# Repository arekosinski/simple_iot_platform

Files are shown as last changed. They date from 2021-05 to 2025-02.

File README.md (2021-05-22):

# simple_iot_system
System for gathering temperature and humidity based on SAM D21, Arduino and nrf24l01. Also Raspberry Pi is involved:)

# Parts of the system
1. Board with MCU, temperature & humidity sensor and radio (nrf24l01)
    * Board is based on Microchip SAM D21 microcontroller
    * You can use Arduino framework to play with this board (this board is Arduino Zero compatible - see more for reference in this [repo](https://github.com/arekosinski/samd21_minimal_board))
    * Radio module slot prepared for nrf24l01
    * Sensor for temp & humidity: SHT31
    * schematic is available in `sensor_schematic` directory. Board design is also attached
    * This board should take around 8-10uA in sleep mode
    * Other components
        * MCP16252 as voltage controller (as boost up). Designed for 2xAA batteries. Input voltage shouldn't excess 3.4V). Board voltage is 3V.
        * MOSFET On Semi FDC6306P (two on board) is used as power controller for radio module and other devices (3 gates)
        * One gate of FDC6306P is used as polarization protection between power source and MCP16252.
2. `sensor_node` - Code responsibile for communication with RF-RPI proxy
3. `rf_rpi_proxy` - Code for the board to act as a UART proxy to Raspberry Pi
4. `rpi_uart_client` - Python UART client resposible for translating received messages

# System diagram

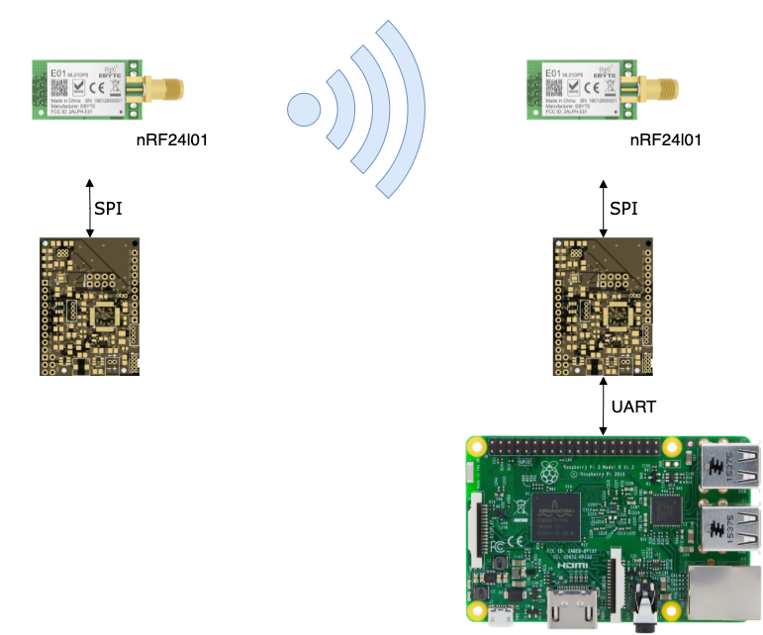
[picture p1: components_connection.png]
Components connection


# Why?
Just for fun :)

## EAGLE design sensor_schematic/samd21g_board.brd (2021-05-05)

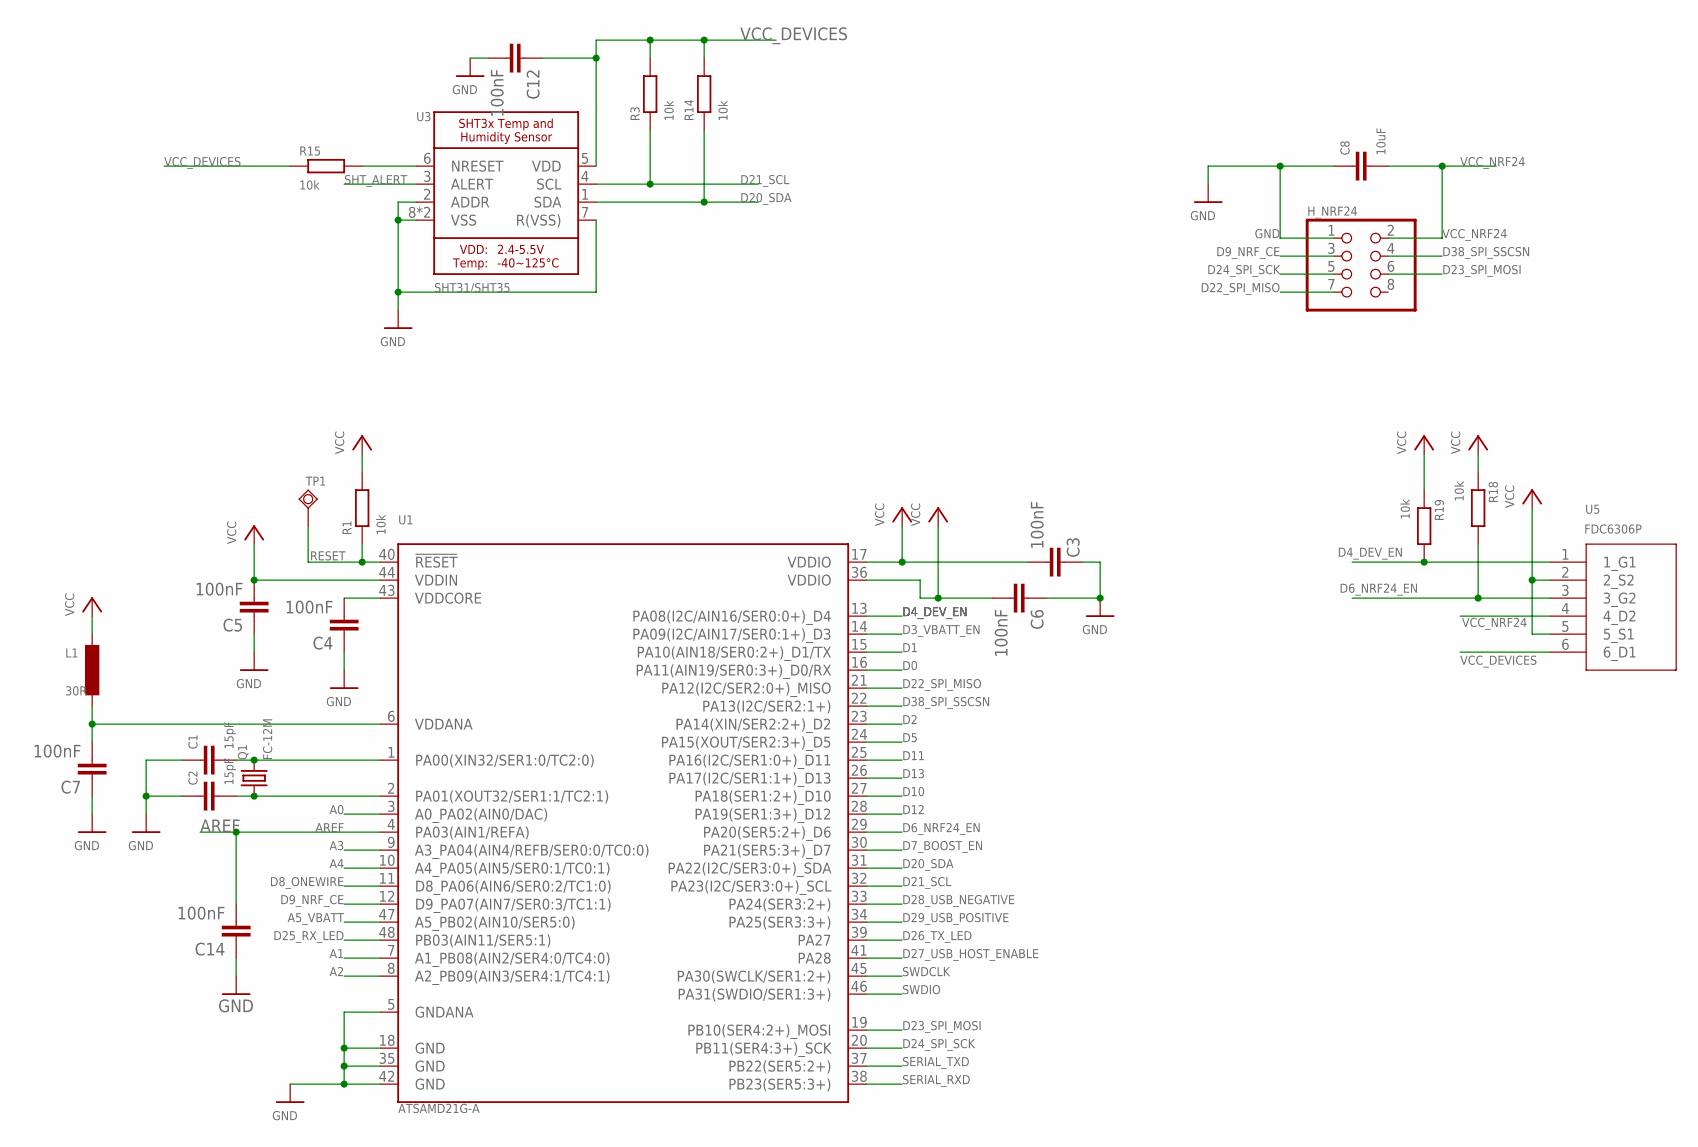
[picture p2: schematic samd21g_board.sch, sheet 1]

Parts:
C1, C2: 15pF; C0402
C3, C4, C5, C6, C7, C12, C14: 100nF; C0603
C8: 10uF; C0805
H_NRF24: PINHD-2X04_2.54; 2X04
L1: 30R; L3225M
Q1: FC-12M
R1, R3, R14, R15, R18, R19: 10k; R0805
TP1: TPSQTP13SQ; TP13SQ
U1: ATSAMD21G-A; TQFP-48
U3: SHT31/SHT35; SHT3X_DFN8
U5: FDC6306P; TSOT23-6_419BL_ONS

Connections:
A0: U1.3 (A0_PA02(AIN0/DAC)); also elsewhere on the board
A1: U1.7 (A1_PB08(AIN2/SER4:0/TC4:0)); also elsewhere on the board
A2: U1.8 (A2_PB09(AIN3/SER4:1/TC4:1)); also elsewhere on the board
A3: U1.9 (A3_PA04(AIN4/REFB/SER0:0/TC0:0)); also elsewhere on the board
A4: U1.10 (A4_PA05(AIN5/SER0:1/TC0:1)); also elsewhere on the board
A5_VBATT: U1.47 (A5_PB02(AIN10/SER5:0)); also elsewhere on the board
AREF: C14.2, U1.4 (PA03(AIN1/REFA)); also elsewhere on the board
D0: U1.16 (PA11(AIN19/SER0:3+)_D0/RX); also elsewhere on the board
D1: U1.15 (PA10(AIN18/SER0:2+)_D1/TX); also elsewhere on the board
D2: U1.23 (PA14(XIN/SER2:2+)_D2); also elsewhere on the board
D3_VBATT_EN: U1.14 (PA09(I2C/AIN17/SER0:1+)_D3); also elsewhere on the board
D4_DEV_EN: R19.2, U1.13 (PA08(I2C/AIN16/SER0:0+)_D4), U5.1 (1_G1)
D5: U1.24 (PA15(XOUT/SER2:3+)_D5); also elsewhere on the board
D6_NRF24_EN: R18.2, U1.29 (PA20(SER5:2+)_D6), U5.3 (3_G2)
D7_BOOST_EN: U1.30 (PA21(SER5:3+)_D7); also elsewhere on the board
D8_ONEWIRE: U1.11 (D8_PA06(AIN6/SER0:2/TC1:0)); also elsewhere on the board
D9_NRF_CE: H_NRF24.3, U1.12 (D9_PA07(AIN7/SER0:3/TC1:1))
D10: U1.27 (PA18(SER1:2+)_D10); also elsewhere on the board
D11: U1.25 (PA16(I2C/SER1:0+)_D11); also elsewhere on the board
D12: U1.28 (PA19(SER1:3+)_D12); also elsewhere on the board
D13: U1.26 (PA17(I2C/SER1:1+)_D13); also elsewhere on the board
D20_SDA: R14.1, U1.31 (PA22(I2C/SER3:0+)_SDA), U3.1 (SDA); also elsewhere on the board
D21_SCL: R3.1, U1.32 (PA23(I2C/SER3:0+)_SCL), U3.4 (SCL); also elsewhere on the board
D22_SPI_MISO: H_NRF24.7, U1.21 (PA12(I2C/SER2:0+)_MISO); also elsewhere on the board
D23_SPI_MOSI: H_NRF24.6, U1.19 (PB10(SER4:2+)_MOSI); also elsewhere on the board
D24_SPI_SCK: H_NRF24.5, U1.20 (PB11(SER4:3+)_SCK); also elsewhere on the board
D25_RX_LED: U1.48 (PB03(AIN11/SER5:1)); also elsewhere on the board
D26_TX_LED: U1.39 (PA27); also elsewhere on the board
D27_USB_HOST_ENABLE: U1.41 (PA28); also elsewhere on the board
D28_USB_NEGATIVE: U1.33 (PA24(SER3:2+)); also elsewhere on the board
D29_USB_POSITIVE: U1.34 (PA25(SER3:3+)); also elsewhere on the board
D38_SPI_SSCSN: H_NRF24.4, U1.22 (PA13(I2C/SER2:1+)); also elsewhere on the board
GND: C1.1, C2.1, C3.1, C4.1, C5.1, C6.1, C7.1, C8.1, C12.2, C14.1, H_NRF24.1, U1.5 (GNDANA), U1.18 (GND), U1.35 (GND), U1.42 (GND), U3.2 (ADDR), U3.7 (R(VSS)), U3.8 (VSS), U3.THERMAL (VSS); also elsewhere on the board
unnamed: C1.2, Q1.2, U1.1 (PA00(XIN32/SER1:0/TC2:0))
unnamed: C2.2, Q1.1, U1.2 (PA01(XOUT32/SER1:1/TC2:1))
unnamed: R15.2, U3.6 (NRESET)
unnamed: C7.2, L1.2, U1.6 (VDDANA)
unnamed: C4.2, U1.43 (VDDCORE)
RESET: R1.1, TP1.TP, U1.40 (!RESET!); also elsewhere on the board
SERIAL_RXD: U1.38 (PB23(SER5:3+)); also elsewhere on the board
SERIAL_TXD: U1.37 (PB22(SER5:2+)); also elsewhere on the board
SHT_ALERT: U3.3 (ALERT); also elsewhere on the board
SWDCLK: U1.45 (PA30(SWCLK/SER1:2+)); also elsewhere on the board
SWDIO: U1.46 (PA31(SWDIO/SER1:3+)); also elsewhere on the board
VCC: C3.2, C5.2, C6.2, L1.1, R1.2, R18.1, R19.1, U1.17 (VDDIO), U1.36 (VDDIO), U1.44 (VDDIN), U5.2 (2_S2), U5.5 (5_S1); also elsewhere on the board
VCC_DEVICES: C12.1, R3.2, R14.2, R15.1, U3.5 (VDD), U5.6 (6_D1); also elsewhere on the board
VCC_NRF24: C8.2, H_NRF24.2, U5.4 (4_D2)

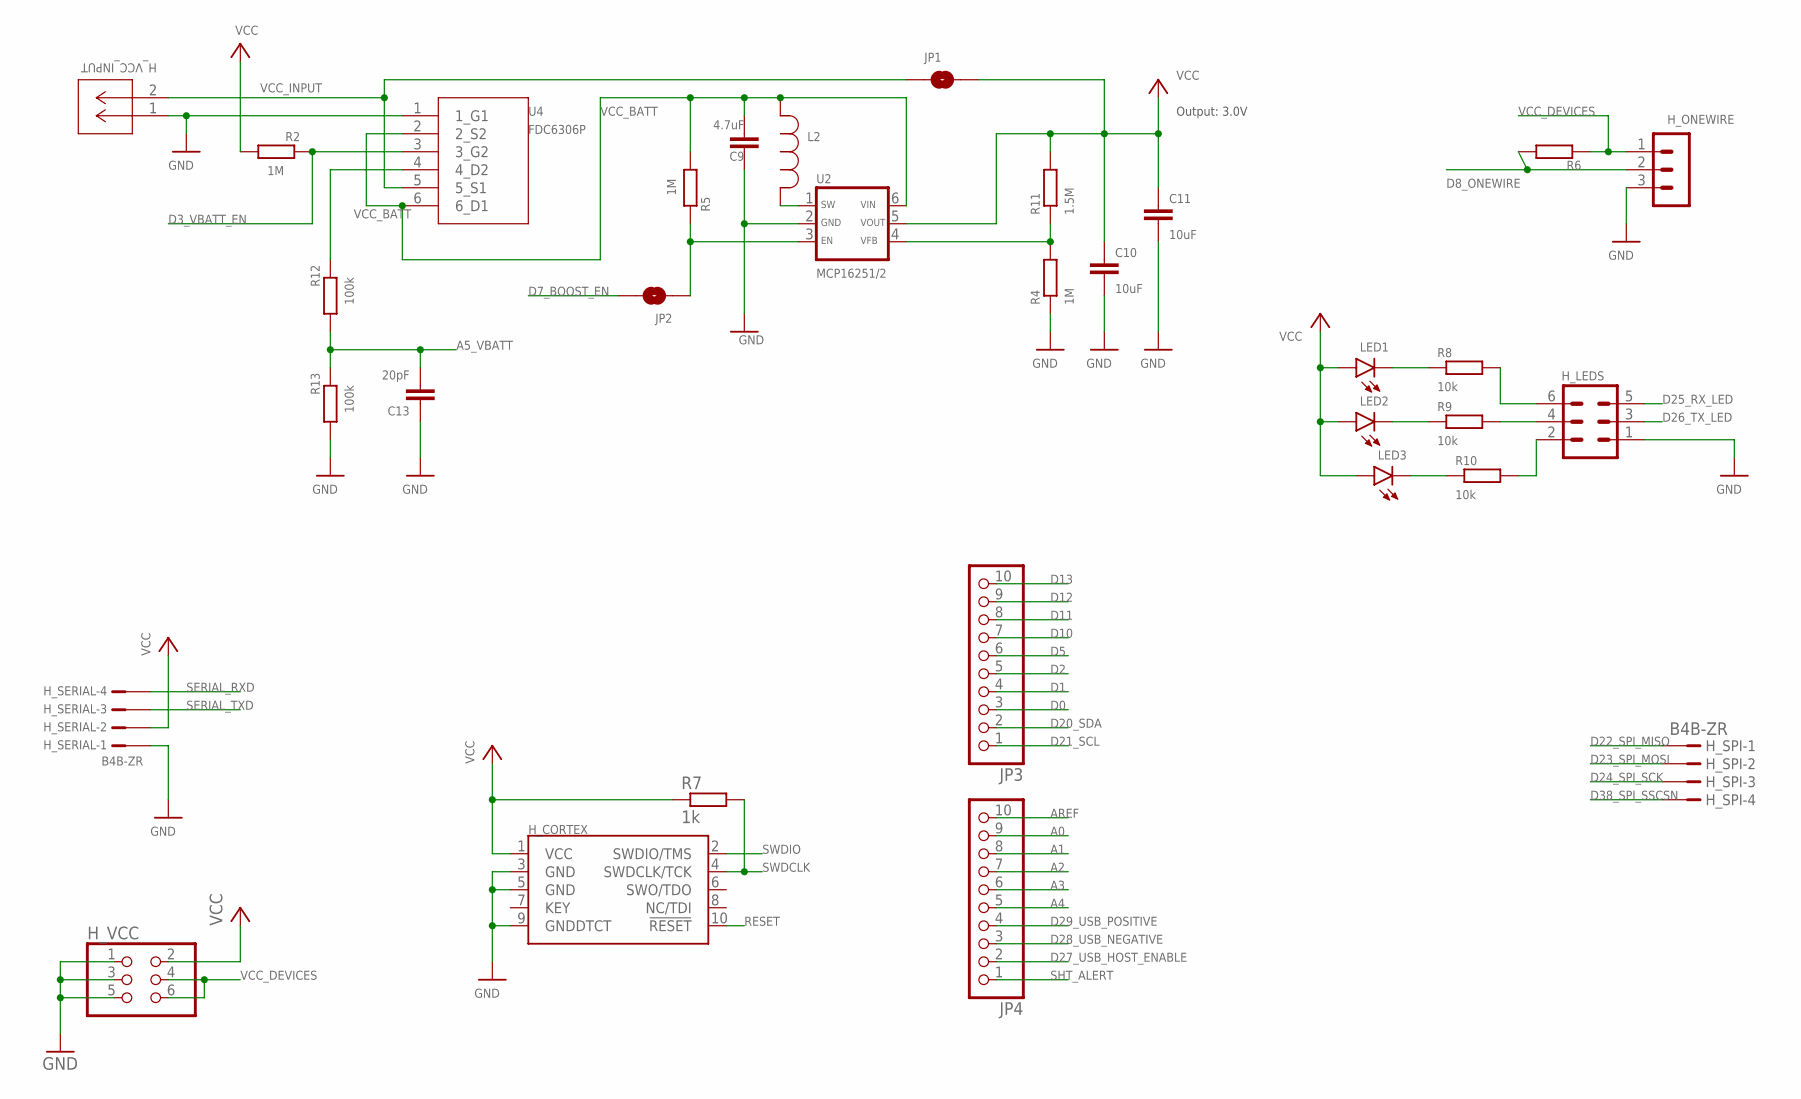
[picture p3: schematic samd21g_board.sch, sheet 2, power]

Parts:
C9: 4.7uF; C0805
C10, C11: 10uF; C0805
C13: 20pF; C0402
H_CORTEX: CORTEX_JTAG_DEBUG_PTH; 2X5-PTH-1.27MM
H_LEDS: M_2R03_50MIL-V2
H_ONEWIRE: M_1R03_50MIL-V
H_SERIAL: B4B-ZR
H_SPI: B4B-ZR
H_VCC: PINHD-2X03_2.54; 2X03
H_VCC_INPUT: S2B-ZR; CONN_S2B-ZR_JST
JP1, JP2: JUMPER-SMT_2_NO_NO-SILK; SMT-JUMPER_2_NO_NO-SILK
JP3, JP4: PINHD-1X10_2.54-S; 1X10-S
L2: 4.7uH; IND_CDRH3D16-4R7NC_SUM
LED1, LED2, LED3: LEDCHIP-LED0805; CHIP-LED0805
R2, R4, R5: 1M; R0805
R6: 4.7k; R0805
R7: 1k; R0805
R8, R9, R10: 10k; R0805
R11: 1.5M; R0805
R12, R13: 100k; R0805
U2: MCP16251/2; SOT-23-6
U4: FDC6306P; TSOT23-6_419BL_ONS

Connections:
A0: JP4.9; also elsewhere on the board
A1: JP4.8; also elsewhere on the board
A2: JP4.7; also elsewhere on the board
A3: JP4.6; also elsewhere on the board
A4: JP4.5; also elsewhere on the board
A5_VBATT: C13.2, R12.1, R13.2; also elsewhere on the board
AREF: JP4.10; also elsewhere on the board
D0: JP3.3; also elsewhere on the board
D1: JP3.4; also elsewhere on the board
D2: JP3.5; also elsewhere on the board
D3_VBATT_EN: R2.2, U4.3 (3_G2); also elsewhere on the board
D5: JP3.6; also elsewhere on the board
D7_BOOST_EN: JP2.2; also elsewhere on the board
D8_ONEWIRE: H_ONEWIRE.2, R6.2; also elsewhere on the board
D10: JP3.7; also elsewhere on the board
D11: JP3.8; also elsewhere on the board
D12: JP3.9; also elsewhere on the board
D13: JP3.10; also elsewhere on the board
D20_SDA: JP3.2; also elsewhere on the board
D21_SCL: JP3.1; also elsewhere on the board
D22_SPI_MISO: H_SPI.1; also elsewhere on the board
D23_SPI_MOSI: H_SPI.2; also elsewhere on the board
D24_SPI_SCK: H_SPI.3; also elsewhere on the board
D25_RX_LED: H_LEDS.5; also elsewhere on the board
D26_TX_LED: H_LEDS.3; also elsewhere on the board
D27_USB_HOST_ENABLE: JP4.2; also elsewhere on the board
D28_USB_NEGATIVE: JP4.3; also elsewhere on the board
D29_USB_POSITIVE: JP4.4; also elsewhere on the board
D38_SPI_SSCSN: H_SPI.4; also elsewhere on the board
GND: C9.1, C10.2, C11.2, C13.1, H_CORTEX.3 (GND), H_CORTEX.5 (GND), H_CORTEX.9 (GNDDTCT), H_LEDS.1, H_ONEWIRE.3, H_SERIAL.1, H_VCC.1, H_VCC.3, H_VCC.5, H_VCC_INPUT.1, R4.1, R13.1, U2.2 (GND), U4.1 (1_G1); also elsewhere on the board
unnamed: H_LEDS.4, R9.2
unnamed: LED2.C, R9.1
unnamed: LED3.C, R10.1
unnamed: LED1.C, R8.1
unnamed: H_LEDS.6, R8.2
unnamed: JP2.1, R5.2, U2.3 (EN)
unnamed: R12.2, U4.4 (4_D2)
unnamed: H_LEDS.2, R10.2
unnamed: R4.2, R11.1, U2.4 (VFB)
unnamed: L2.1, U2.1 (SW)
RESET: H_CORTEX.10 (!RESET); also elsewhere on the board
SERIAL_RXD: H_SERIAL.4; also elsewhere on the board
SERIAL_TXD: H_SERIAL.3; also elsewhere on the board
SHT_ALERT: JP4.1; also elsewhere on the board
SWDCLK: H_CORTEX.4 (SWDCLK/TCK), R7.2; also elsewhere on the board
SWDIO: H_CORTEX.2 (SWDIO/TMS); also elsewhere on the board
VCC: C10.1, C11.1, H_CORTEX.1 (VCC), H_SERIAL.2, H_VCC.2, JP1.2, LED1.A, LED2.A, LED3.A, R2.1, R7.1, R11.2, U2.5 (VOUT); also elsewhere on the board
VCC_BATT: C9.2, L2.2, R5.1, U2.6 (VIN), U4.2 (2_S2), U4.6 (6_D1)
VCC_DEVICES: H_ONEWIRE.1, H_VCC.4, H_VCC.6, R6.1; also elsewhere on the board
VCC_INPUT: H_VCC_INPUT.2, JP1.1, U4.5 (5_S1)

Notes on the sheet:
Output: 3.0V

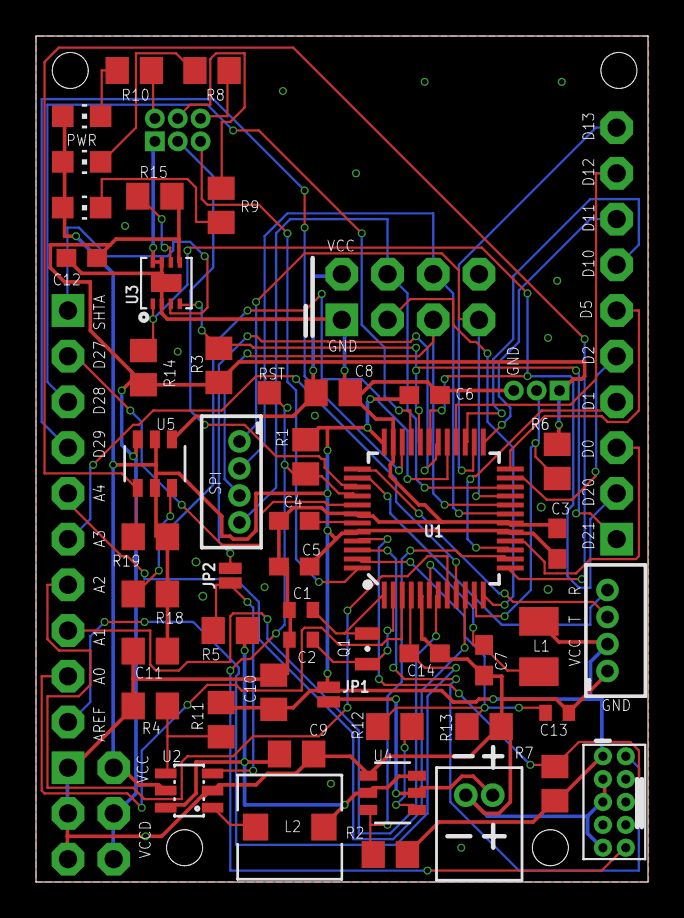
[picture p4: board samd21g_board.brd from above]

Board: 2 copper layers, 34.0 x 47.0 mm, 55 parts (0 on the bottom side), 59 nets.

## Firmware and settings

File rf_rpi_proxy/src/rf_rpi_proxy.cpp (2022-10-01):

#include <Arduino.h>

// define board pins according to arduino pins schema
#define LED_BUILTIN      (25ul)   // User controlled LED1 Arduino: D25 / Board: D25_RX_LED/PB03
#define LED_BUILTIN_1    LED_BUILTIN
#define LED_BULITIN_2    (26ul)   // User controlled LED2 Arduino: D26 / Board: D26_TX_LED/PA27
#define PIN_RADIO_EN     (6ul)	 // Pin to control radio power MOSFET / Arduino: D6 / Board: D6_NRF24_EN/PA20

// system behavior
#define SERIAL_BAUDS     (115200ul)	// UART Speed for debugging header (Arduino: Serial object)
#define RPI_SERIAL_BAUDS (230400ul) // UART Speed for communication with Raspberry Pi (Arduino: Serial1 object)

uint8_t is_debug_initialized = 0;

// headers for NRF24 library
#include <SPI.h>
#include "RF24.h"

// communication
#define R_PIN_CE         (9ul)		  // Arduino: D9 / Board: D9_NRF_CE/PA07
#define R_PIN_CSN        (38ul)		  // Arduino: D38 / Board: D38_SPI_SSCSN/PA13
#define R_ADDR_RX        (0x696900)	  // Address on which we must listen to get messages from remote nodes (on remote nodes this is TX address)
#define R_ADDR_WIDTH     (3ul)		  // We can limit frame by using shorter address
#define R_CHANNEL        (20ul)		  // Channel number from 2.4GHz range
#define R_POWER_LVL      RF24_PA_MAX  // Output power during sending
#define R_DATA_RATE      RF24_250KBPS // Data rate used over the air
#define R_MSG_DELAY      (50ul)		  // Check description of setRetries function for meaning of this value
#define R_MSG_RETRIES    (10ul)	      // Check description of setRetries function for meaning of this value

RF24 radio(R_PIN_CE, R_PIN_CSN);

/*
Enum with definition of possible system restart. User should be aware of what kind of reboot occurred.
1 - System reset
2 - External reset requested (some one pushedreset button)
3 - BOD 3.3V
4 - BOD 1.2V
5 - Normal power on reset - system is starting by its standard procedure
6 - WDT Reset
99 - Unknown / very very sad face :(
*/
typedef enum {
    /** (0) System reset */
    RBT_SYSTEM = 0,
    /** (1) External reset (reset pin) */
    RBT_EXTERNAL_RESET,
    /** (2) BOD 3.3V */
    RBT_BOD3V3,
    /** (3) BOD 1.2V */
    RBT_BOD1V2,
    /** (4) Normaln power on reset - standard */
    RBT_STARTUP,
    /** (6) WDT */
    RBT_WDT,
    RBT_UNKNOWN = 99
} startup_code_ref;

//
// debugging 
template <typename... T>
void debug_me(const char *str, T... args) {
#ifdef DEBUG_ENABLED
	if ( is_debug_initialized == 1 ) {
		int len = snprintf(NULL, 0, str, args...);
		if (len) {
			char buff[len] = {0};
			sprintf(buff, str, args...);
			Serial.print(buff);
		};
		Serial.println();
	};
#endif
}

void enable_debug_mode() {
#ifdef DEBUG_ENABLED
	PM->APBCMASK.reg |= PM_APBCMASK_SERCOM5;	
    Serial.begin(SERIAL_BAUDS);
	debug_me("----------------------------");
	debug_me("Debug enabled");
	is_debug_initialized = 1;
#endif
}

void disable_debug_mode() {
#ifdef DEBUG_ENABLED
	Serial.end();
	is_debug_initialized = 0;
#endif
}
// END debugging

startup_code_ref get_last_reset_cause() {
	if (PM->RCAUSE.bit.SYST == 1)
	{
		debug_me("Reboot: Reset requested by system");
		return RBT_SYSTEM;
	};
	if (PM->RCAUSE.reg & PM_RCAUSE_WDT)
	{
		debug_me("Reboot: WDT");
		return RBT_WDT;
	};
	if (PM->RCAUSE.bit.EXT == 1)
	{
		debug_me("Reboot: External reset requested");
		return RBT_EXTERNAL_RESET;
	};
	if (PM->RCAUSE.bit.BOD33 == 1)
	{
		debug_me("Reboot: Reset brown out 3.3V");
		return RBT_BOD3V3;
	};
	if (PM->RCAUSE.bit.BOD12 == 1)
	{
		debug_me("Reboot: Reset brown out 1.2v");
		return RBT_BOD1V2;
	};
	if (PM->RCAUSE.bit.POR == 1)
	{
		debug_me("Reboot: Normal power on reset");
		return RBT_STARTUP;
	};
	debug_me("Reboot: unknown reason");
	return RBT_UNKNOWN;
}

//
// basic function to shorthand (wrap) enabling and disabling devices
void enable_equipment(const uint8_t pinNumber, const PinStatus state = HIGH, const PinMode mode = OUTPUT) {
	debug_me("Enabling eq pin:%i state:%i mode:%i", pinNumber, state, mode);
	pinMode(pinNumber, mode);
	digitalWrite(pinNumber, state);
}

void disable_equipment(const uint8_t pinNumber, const PinStatus state = LOW, const PinMode mode = INPUT_PULLUP) {
	debug_me("Disabling eq pin:%i state:%i mode:%i", pinNumber, state, mode);
	digitalWrite(pinNumber, state);
	pinMode(pinNumber, mode);
}

// making LED blinking a bit easier
void say_hello_world(const int cycles_count = 2, const int delay_ms = 300, const int led_port = LED_BUILTIN) {
	for (int i = 0; i < cycles_count; i++)
	{
		enable_equipment(led_port, LOW);
		delay(delay_ms);
		disable_equipment(led_port, HIGH);
		if (i + 1 < cycles_count)
		{
			delay(delay_ms);
		};
	};
}


// configure radio
void init_radio() {
	enable_equipment(PIN_RADIO_EN, RADIO_EN_PIN_STATE, OUTPUT);
	delay(100);
	bool radio_being_status = radio.begin();
	if (!radio_being_status)
	{ // Radio failed to init. Give some time and perform reboot
		debug_me("Radio problem");
		say_hello_world(100, 200, LED_BUILTIN_1);
		NVIC_SystemReset();
	};

	radio.enableDynamicPayloads();

	radio.setAutoAck(true);
	radio.setChannel(R_CHANNEL);
	radio.setAddressWidth(R_ADDR_WIDTH);
	radio.setPALevel(R_POWER_LVL);
	radio.setDataRate(R_DATA_RATE);
	radio.setRetries(R_MSG_DELAY, R_MSG_RETRIES);

	radio.openReadingPipe(1, R_ADDR_RX);

#ifdef DEBUG_ENABLED
	radio.printDetails();
	radio.printPrettyDetails();
#endif

	radio.startListening();
}
// radio functions


void loop() {
	debug_me("Start listening for new messages");
	radio.startListening();
	char msg[33] = {'\0'}; // max possible message size is 32bytes for nrf24l01

	while (!radio.available())
	{
		// waiting for new message
		// TODO: in next version we should use interrupt from NRF to handle newly arrived messages
	};

	// process new message
	if (radio.available())
	{
		uint8_t msg_len = radio.getDynamicPayloadSize();
		radio.read(&msg, msg_len);
		Serial1.println(msg);
#ifdef DEBUG_ENABLED
		debug_me(msg);
		say_hello_world(1, 10, LED_BULITIN_2);
#endif
	};
}

void setup(void) {

	enable_debug_mode();
	debug_me("System start");
	say_hello_world(3, 200);

	startup_code_ref startup_code = get_last_reset_cause();

	Serial1.begin(RPI_SERIAL_BAUDS);
	// say hi to Raspberry Pi
	Serial1.println("X: Welcome");
	Serial1.print("X: Last reboot code: ");
	Serial1.println(startup_code);
	init_radio();
}

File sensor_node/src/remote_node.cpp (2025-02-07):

#include <Arduino.h>
#include <wiring_private.h>
extern "C" void __libc_init_array(void);

#define VARIANT_MCK (8000000ul) // this is core speed we will work at - 8MHz
#define F_CPU VARIANT_MCK // for compatibility with Arduino frameworks

// rtc requirement
#include "RTCZero.h"

RTCZero rtc;

// Change these values to set the current initial date
const byte seconds = 0;
const byte minutes = 00;
const byte hours = 0;
const byte day = 1;
const byte month = 1;
const unsigned int year = 21;

#include "global_counter.h"

GlobalCounter gcnt;


// dictionaries
/*
Enum with definition of possible system restart. User should be aware of what kind of reboot occurred.
1 - System reset
2 - External reset requested (some one pushedreset button)
3 - BOD 3.3V
4 - BOD 1.2V
5 - Normal power on reset - system is starting by its standard procedure
6 - WDT Reset
99 - Unknown / very very sad face :(
*/
typedef enum e_platform_reboot_codes_definition
{
	RBT_SYSTEM = 0,		/** (0) System reset */
	RBT_EXTERNAL_RESET, /** (1) External reset (reset pin) */
	RBT_BOD3V3,			/** (2) BOD 3.3V */
	RBT_BOD1V2,			/** (3) BOD 1.2V */
	RBT_STARTUP,		/** (4) Normaln power on reset - standard */
	RBT_WDT,			/** (5) WDT */
	RBT_UNKNOWN = 99
} startup_code_ref;

/*
Enum with definition of measurments code
*/
typedef enum e_message_content_codes_definition
{
	MSGC_TEMPERATURE = 0x1,
	MSGC_HUMIDITY = 0x2,
	MSGC_BATTERY_VOLTAGE = 0x3,
	MSGC_TEMP_SENSOR_ERROR = 0x4,
	MSGC_ALL_MESSAGES_SUCCESS = 0x5,
	MSGC_ALL_SENDING_TRIALS = 0x6,
	MSGC_AVG_CYCLE_LENGTH = 0x7,
	MSGC_DELIVERY_RATIO = 0x8,
	MSGC_RETRANSMISSIONS = 0x9,
	MSGC_ACCU_VOLTAGE = 0xA,
	MSGC_ID_1 = 0xB,
	MSGC_ID_2 = 0xC,
	MSGC_ID_3 = 0xD,
	MSGC_ID_4 = 0xE,
	MSGC_STARTUP_CODE = 0xF
	// for further use:
	// 0x0
} message_content_ref;

// define board pins according to arduino pins schema & board design
#define LED_BUILTIN				PIN_LED_RXL // Arduino: D25 / SAM D21: PB03
#define LED_BUILTIN_1 			PIN_LED_RXL
#define LED_BUILTIN_2 			PIN_LED_TXL // Arduino: D26 / SAM D21: PA27
#define PIN_RADIO_EN 			(6ul) // Arduino: D6 / SAM D21: PA20
#define PIN_ONEWIRE_DQ 			(8ul) // Arduino: D8 / SAM D21: PA06
#define PIN_BOOST_EN 			(7ul) // Arduino: D7 / SAM D21: PA21
#define PIN_SENSORS_EN 			(4ul) // Arduino: D4 / SAM D21: PA08
#define PIN_VBATT_EN 			(3ul) // Arduino: D3 / SAM D21: PA09
#define PIN_BATTERY_VOLTAGE 	(A5)  // Arduino: A5 / SAM D21: PB02

// system behavior
// clock multiplexers used
// RTC - 2
// WDT - 3
// SERCOM3 - GCLK0
// SERCOM5 - GCLK0
#define GCLK_UNUSED_FOR_EVER 	GCLK_CLKCTRL_GEN_GCLK7_Val // which GCLK will be never used - we can connect all devices to this one
#define GCLK_USED_FOR_RTC 		GCLK_CLKCTRL_GEN_GCLK2_Val	// clock used for RTC - required to wake up. always must be enabled
#define GCLK_USED_FOR_WDT 		GCLK_CLKCTRL_GEN_GCLK3_Val	// clock used for RTC - required to wake up. always must be enabled
#define SERIAL_BAUDS			(38400ul) // connection speed for debug purposes
#ifndef GLOBAL_SLEEP_SECONDS
	#define GLOBAL_SLEEP_SECONDS (60*6ul)
#endif
uint_fast8_t is_debug_initialized = 0;
uint_fast8_t startup_reset_cause = 0;
uint_fast32_t mcu_unique_id[4]; // in this place we will keep unique identifier of our board
uint8_t my_node_id = 0;			// ID of this board - calculated from mcu_unique_id
#ifndef BOARD_VCC_STABLE
	#define BOARD_VCC_STABLE 			(3.05F) // required for ADC measurments (VCC is source for voltage divider)
#endif
#ifndef STATS_SENDER_CYCLES // after how many cycles performance statistics should be sent
	#define STATS_SENDER_CYCLES (20ul)
#endif

// including stuff required for communication over NRF24 module
#include <SPI.h>
#include <nRF24L01.h>
#include <RF24.h>

// NRF24 and communication layer settings
#define R_PIN_CE 				(9ul)
#define R_PIN_CSN				(38ul)
#define R_ADDR_TX 				(0x696900)
#define R_ADDR_RX_COMMON 		(0xAA0000) // common part of each node. To this constant we are adding custom node id value
#define R_ADDR_WIDTH 			(3ul)
#define R_CHANNEL 				(99ul)
#ifndef R_POWER_LVL
	#define R_POWER_LVL 		RF24_PA_HIGH
#endif
#define R_DATA_RATE 			RF24_250KBPS
#define R_RETRIES_DELAY 		(50ul)  // see documentation for setRetires function
#define R_RETRIES_COUNT 		(5ul) // see documentation for setRetires function
#define MSG_SEP 				"|"
#define R_MSG_MAX_REPEAT 		(3ul) // how many time try of sending message should be taken - additional wrapping of write function
RF24 radio(R_PIN_CE, R_PIN_CSN);

// including stuff required for Sensirion SHT31 sensor
#include <Wire.h>
#include "Adafruit_SHT31.h"
#define SHT31_ENABLE_HEATER 	(false)

Adafruit_SHT31 sht31 = Adafruit_SHT31();

// END OF DECLARATIONS / real magic begins :)

// clocks configuration functions
// OSC setup and main clock setup - configure main system clock at 8MHz speed
void init_OSC8M()
{														  
	SYSCTRL->OSC8M.bit.PRESC = SYSCTRL_OSC8M_PRESC_0_Val; // no prescaller / it should be 8MHz
	SYSCTRL->OSC8M.bit.ONDEMAND = 0;
	SYSCTRL->OSC8M.bit.RUNSTDBY = 0;
	SYSCTRL->OSC8M.bit.ENABLE = 1;
	while ((SYSCTRL->PCLKSR.reg & SYSCTRL_PCLKSR_OSC8MRDY) == 0);
}

void init_GCLK_MAIN()
{
	GCLK->GENDIV.reg = GCLK_GENDIV_ID(GCLK_CLKCTRL_GEN_GCLK0); // Generic Clock Generator 0

	while (GCLK->STATUS.reg & GCLK_STATUS_SYNCBUSY);

	/* Write Generic Clock Generator 0 configuration */
	GCLK->GENCTRL.reg = GCLK_GENCTRL_ID(GCLK_CLKCTRL_GEN_GCLK0) | // Generic Clock Generator 0
						GCLK_GENCTRL_SRC_OSC8M |				  // source for main clock generator is OSC8M
						GCLK_GENCTRL_IDC |						  // Set 50/50 duty cycle
						GCLK_GENCTRL_GENEN;

	while (GCLK->STATUS.reg & GCLK_STATUS_SYNCBUSY);
}

void disable_general_clock(uint8_t gclk)
{
	GCLK->GENCTRL.reg = GCLK_GENCTRL_ID(gclk);
	while (GCLK->STATUS.reg & GCLK_STATUS_SYNCBUSY);
}

// debuging function
template <typename... T>
void debug_me(const char *str, T... args)
{
#ifdef DEBUG_ENABLED
	if (is_debug_initialized == 1)
	{
		int len = snprintf(NULL, 0, str, args...);
		if (len)
		{
			char buffm[len] = {0};
			sprintf(buffm, str, args...);
			Serial.print(buffm);
		};
		Serial.println();
		delay(8);
	};
#endif
}

void enable_debug_mode()
{
	PM->APBCMASK.reg |= PM_APBCMASK_SERCOM5;
	Serial.begin(SERIAL_BAUDS);
	is_debug_initialized = 1;
}

void disable_debug_mode()
{
	Serial.end();
	PM->APBCMASK.reg &= ~PM_APBCMASK_SERCOM5;
	is_debug_initialized = 0;
}

void get_unique_id()
{
	volatile uint32_t *ptr1 = (volatile uint32_t *)0x0080A00C;
	mcu_unique_id[0] = *ptr1;
	volatile uint32_t *ptr = (volatile uint32_t *)0x0080A040;
	mcu_unique_id[1] = *ptr;
	ptr++;
	mcu_unique_id[2] = *ptr;
	ptr++;
	mcu_unique_id[3] = *ptr;

	debug_me("MCU unique ID: 0x%8x%8x%8x%8x", mcu_unique_id[0], mcu_unique_id[1], mcu_unique_id[2], mcu_unique_id[3]);

	#if defined(CUSTOM_NODE_ID)
		my_node_id = (uint8_t)CUSTOM_NODE_ID;
	#else
		my_node_id = mcu_unique_id[0] % 64 + mcu_unique_id[1] % 64 + mcu_unique_id[2] % 64 + mcu_unique_id[3] % 64;
	#endif

	debug_me("My NODE_ID: %i / %x ", my_node_id, my_node_id);
}
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

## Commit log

2021-05-05 initial version of small board based on SAM D21 with schematic and code for transmitter and receiver
    [samd21g_board.brd, samd21g_board.sch]
2021-05-13 cleaning up repo
    [samd21g_board.brd, samd21g_board.sch]
2021-05-17 communication between board and RPi over UART
2021-06-11 addig watchdog features and small fixes
    [remote_node.cpp]
2021-10-14 adding additional power source - accu charged from solar panels
2022-10-01 adjust serial speed to board

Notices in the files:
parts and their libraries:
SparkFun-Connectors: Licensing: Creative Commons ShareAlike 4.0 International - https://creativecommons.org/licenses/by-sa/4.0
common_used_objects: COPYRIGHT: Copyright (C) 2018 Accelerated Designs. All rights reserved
